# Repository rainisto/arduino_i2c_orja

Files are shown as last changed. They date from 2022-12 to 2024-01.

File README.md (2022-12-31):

# arduino_i2c_orja
Danfoss heat pump USB based control interface, which mimics ThermIQ-USB functionality.

# Background

In 2015 I did a blog post where I reverse engineered the i2c protocol which Dandfoss and Thermia pumps are using (sorry post is in Finnish):

https://omakotikotitalomme.blogspot.com/2015/03/danfoss-lampopumpun-salaisuudet.html    

And finally I decided that its time to open source the source code and release updated gerber files which makes it easier to use (with Arduino Nano or Arduino pro mini). Hopefully this will allow cheap alternatives for controlling Danfoss heap pumps. Use at your own risk, don't blame me if you break your device. Always turn off the devices before connecting the i2c cable.    

I know that the code is not very beatiful and optimized, but it works. If you find bugs feel free to make merge request with a fix. Unfortunately I'm currently not able to give much support for this project, as I'm focusing on coding ESP32 based version which will add wifi and ROOM thermometer emulation support (similar functionality as MQTT based ThermIQ-ROOM2LP).

# Software alternatives for usage

Implementation has been tested with taloLogger, ThermIQ and ThermIQ2-Web. Please don't ask support from thermiq.net as this is not their hardware (so there is no official support for it) this just happends to mimic the same AT-command functionality. I've been running it 5+ years without problems. And of course you can use for example minicom to run AT-commands manually.

TaloLogger instructions:    
- https://olammi.iki.fi/sw/taloLoggerPi/howto.php     
- https://olammi.iki.fi/sw/taloLogger/

V1 version install instructions:    
- https://www.thermiq.net/wp-conteny/uploads/ThermIQ-installation-for-Raspberry-PI.pdf  (does not require license)

V2 version install instructions:    
- https://www.thermiq.net/en/sw/raspberry-pi/ (requires license which can be purchased from https://www.thermiq.net/en/produkt/thermiq2-web/ )

In theory it should also work with home assistant integration (but I haven't had time to test it):    
- https://github.com/tomrosenback/thermiq-node-red-homeassistant-config    
- https://github.com/ThermIQ/thermiq_mqtt-ha

# Building arduino hex firmware on Linux with Docker

You need to have Docker installed on your Linux machine and then run:

- ./linux_build.sh    

Resulting .hex files will be found under hex-directory after the build. You can use for example avrdude to flash it:    
- avrdude -v -p atmega328p -c arduino -P /dev/ttyUSB0 -b 57600 -D -U flash:w:i2c_rtc_simplified_with_watchdog_nano.ino.hex:i

# Building with Arduino IDE (Linux and Windows):
Install package depencies (Wire, NeoSWSerial and AltSoftSerial) before the build.

# Hardware with gerber pcb

Arduino Nano is prefered over Arduino Pro mini and serial ttl adapter, as its cheaper just to use Arduino Nano to power the device as compared to Pro mini and serial ttl adapter. Serial2 and Serial3 are optional adapters which can be used for example if you want to simultaneously use several serial connections with TaloLogger and ThermIQ web interfaces at the same time. Nano variant use 220uF capacitor to prevent rebooting when connecting to 1st serial port (unplug the capacitor during firmware flashing).

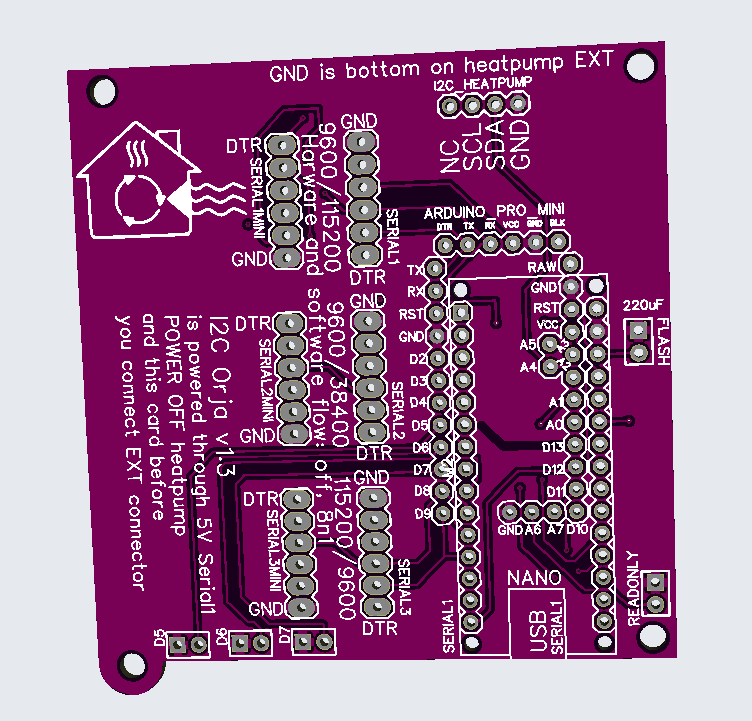
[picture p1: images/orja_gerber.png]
Orja Gerber


There is RO pins for ReadOnly mode (if you want to prevent write commands and are only gathering usage data).    
And there are serial speed controlling pins for switching between serial speeds (but most likely you want to stay at 9600 if you want to use the existing software backends).

There is a stl file for simple 3d printed screw-mount which will help protecting against short circuits against metal parts.

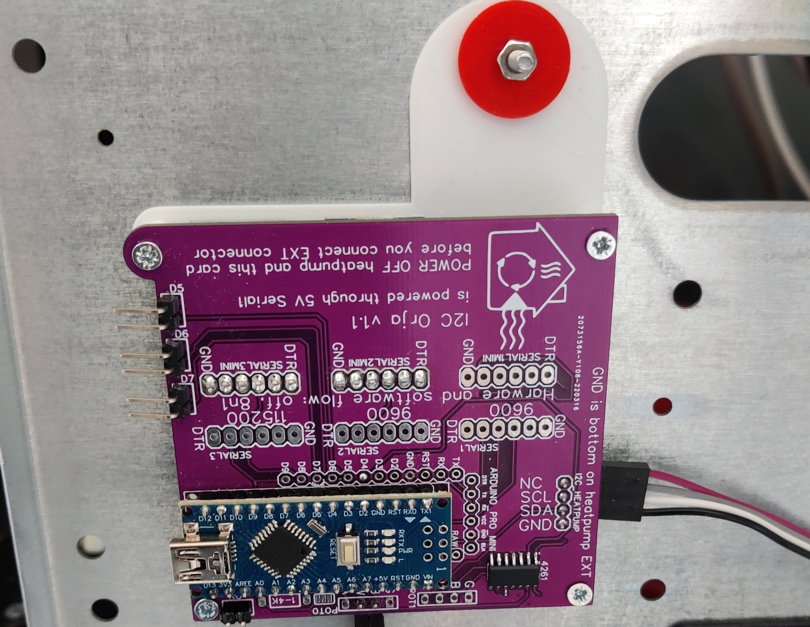
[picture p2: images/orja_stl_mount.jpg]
Orja Mount

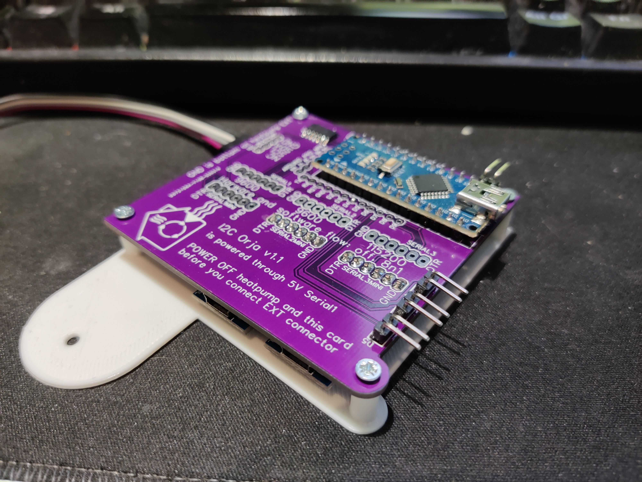
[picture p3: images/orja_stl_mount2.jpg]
Orja Mount2

Orja Mount3

# BOM

BOM is around 10-20euroes depending where you source the hardware.

- Arduino Nano (recommended) or Arduino Pro mini (5V 16Mhz)    
- Serial ttl usb adapter(s) 5V (optional)    
- 4p dupont cable (for i2c connection)    
- 2.54mm header angle pins   
- 220uF capacitor for preventing Nano reseting when starting serial connection.

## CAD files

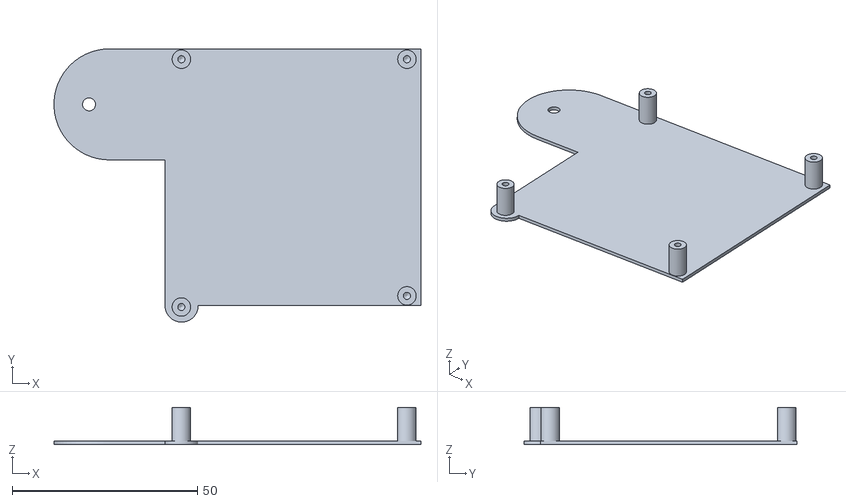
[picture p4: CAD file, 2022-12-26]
hardware/stl/I2C_orja.stl
99.2 x 73.8 x 10.0

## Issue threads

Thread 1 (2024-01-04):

Register 7F?

jukkapirinen, 2024-01-04:
I just started testing this, I can read the data but getting spammed with the data for register 7F all the time.

What is this register 7F (127) and value 0002?
And what are those empty requests?

```
$ cat /dev/serial/by-id/usb-1a86_USB_Serial-if00-port0 |ts  '%Y%m%d-%H:%M:%.S'
20240105-00:52:04.371242 7F=0002
20240105-00:52:04.371347 empty request
20240105-00:52:04.371390 7F=0002
20240105-00:52:04.371422 7F=0002
20240105-00:52:04.371451 7F=0002
20240105-00:52:04.371481 7F=0002
20240105-00:52:04.688652 7F=0002
20240105-00:52:04.688732 7F=0002
20240105-00:52:04.688756 empty request
20240105-00:52:04.688776 empty request
20240105-00:52:05.164298 7F=0002
20240105-00:52:05.164427 7F=0002
20240105-00:52:05.164474 7F=0002
20240105-00:52:05.164512 7F=0002
20240105-00:52:05.164577 7F=0002
20240105-00:52:05.164612 7F=0002
20240105-00:52:05.164646 7F=0002
20240105-00:52:05.243292 7F=0002
20240105-00:52:05.243397 7F=0002
20240105-00:52:05.243430 7F=0002
20240105-00:52:05.243456 7F=0002
20240105-00:52:05.243481 7F=0002
20240105-00:52:05.243509 7F=0002
20240105-00:52:05.243535 7F=0002
20240105-00:52:05.408361 7F=0002
20240105-00:52:05.408489 7F=0002
20240105-00:52:05.408548 7F=0002
20240105-00:52:05.408582 7F=0002
20240105-00:52:05.408612 7F=0002
20240105-00:52:05.408641 empty request
20240105-00:52:05.487329 7F=0002
20240105-00:52:05.487399 7F=0002
20240105-00:52:05.487414 7F=0002
20240105-00:52:05.487426 7F=0002
20240105-00:52:05.487438 7F=0002
20240105-00:52:05.487448 7F=0002
20240105-00:52:05.487459 7F=0002
```

rainisto, 2024-01-04:
7f is max register, maybe you have accidentally asked that value, and request is not cleared. Maybe off by one bug in code, as usually 74 is the last register that has usable data. What kind of query steps have you made to trigger that? empty request is just debug if wire library doesn't have data. So might also be arduino ide or library version issue.

jukkapirinen, 2024-01-05:
Yes that fixes the initialize, but the real issue was that the readQueue array was too small (0-127= 128) and created infinite loop.

int readQueue[MAX_REGISTER + 1];

https://github.com/jukkapirinen/arduino_i2c_orja/commit/e5ff0c0d8ccd08068f233ab1cf81ee704d306a35

jukkapirinen, 2024-01-05:
And I did not ask for that value or any value. Just connected to pump and then cat / screen to view the serial output. However now it works with the above changes and also got working with Home Assistant + NodeRED + ThermIQ MQTT Integration

rainisto, 2024-01-05:
Thanks for the info, I pushed fix to git.

Closed 2024-01-05.

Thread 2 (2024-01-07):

Room sensor emulation

andresmihkelson, 2024-01-07:
Thank You for all the good work on reverse engineering the I2C communication on the EXT port.

You have mentioned in couple of forums that You also got the indoor room sensor interface (pins 303/304) working. Can You share any details on how it is implemented?

rainisto, 2024-01-07:
It will be 2 part blog post, second part will still take some more time before its ready for publishing. But I guess the 1 / 2 part is ready (so I published it now) which will tell the logic analyzing and solving out that it was Manchester code variant and how the protocol works in paper. Its in Finnish so you'll need to use google translator. https://omakotikotitalomme.blogspot.com/2024/01/danfoss-sisalampotilasensorin.html

andresmihkelson, 2024-01-07:
Thanks!

Closed 2024-01-07.

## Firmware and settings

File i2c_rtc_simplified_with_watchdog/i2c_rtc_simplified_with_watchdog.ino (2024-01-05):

/* 
 * This file is part of the Arduino i2c orja distribution (https://github.com/rainisto/arduino_i2c_orja)
 * Copyright (c) 2015-2022 Jonni Rainisto (rainisto@iki.fi)
 * 
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
 * You should have received a copy of the GNU General Public License 
 * along with this program. If not, see <http://www.gnu.org/licenses/>.
 */

#include <Wire.h>
#include <AltSoftSerial.h>
#include <NeoSWSerial.h>
#include <avr/wdt.h>

NeoSWSerial serial2(3,4);    // RX, TX
AltSoftSerial serial3;       // 8, 9

enum { 
  I2C_CMD_PING_BOOT = 0xfd,
  I2C_CMD_PING_QUERY = 0xfe
};
extern const byte supportedI2Ccmd[] = { 
  I2C_CMD_PING_BOOT, I2C_CMD_PING_QUERY
};

enum { 
  I2C_MSG_ARGS_MAX = 3,
  I2C_RESP_LEN_MAX = 3
};
#define TWI_FREQ_SETTING         400000L       // 400KHz for I2C
#define CPU_FREQ                 16000000L     // 16MHz
#define SLAVE_ADDRESS            0x2e
byte zero = 0x00;                              //workaround for issue #527
#define MAX_REGISTER             0x7F
byte previousRequest=0x0;

byte writeMask=0x80;
byte writeAddress=0x0;
byte writeHigh=0x0;
byte writeLow=0x0;
int writeOrigin=0;
int roPinValue=0;

int okPending=0;

int readQueue[MAX_REGISTER+1];

int argsCnt = 0;                        // how many arguments were passed with given command
int requestedCmd = -1;                  // which command was requested (if any)

byte i2cArgs[I2C_MSG_ARGS_MAX];         // array to store args received from master
int i2cArgsLen = 0;                     // how many args passed by master to given command

uint8_t i2cResponse[I2C_RESP_LEN_MAX];  // array to store response
int i2cResponseLen = 0;                 // response length

void setup()
{
  delay(1000); 
  // TWBR = ((CPU_FREQ / TWI_FREQ_SETTING) - 16) / 2;
  Wire.begin(SLAVE_ADDRESS);
  int i;

  // Initialize readQueue
  for (i=0; i <= MAX_REGISTER; i++) {
    readQueue[i]=0;
  }
  // config pins
  pinMode(5, INPUT_PULLUP);
  pinMode(6, INPUT_PULLUP);
  pinMode(7, INPUT_PULLUP);

  // Initialize serial ports
  if (digitalRead(5)) {
    Serial.begin(9600);
  } else {
    Serial.begin(115200);
  }
  Serial.println(F("\nI2C Orja v1.0 (serial1)"));
  if (digitalRead(6)) {
    serial2.begin(9600);
  } else {
    serial2.begin(38400);
  }
  serial2.println(F("\nI2C Orja (serial2)"));
  if (digitalRead(7)) {
    serial3.begin(115200);
  } else {
    serial3.begin(9600);
  }
  serial3.println(F("\nI2C Orja (serial3)"));

  Wire.onRequest(requestEvent); // register event handlers
  Wire.onReceive(receiveEvent); // register event handlers
  wdt_enable(WDTO_8S);          // enable watchdog
}

byte getVal(char c)
{
   if(c >= '0' && c <= '9') return (byte)(c - '0');
   else return (byte)(c-'A'+10);
}

void requestEvent(){
  Wire.write(i2cResponse, i2cResponseLen);
}

void receiveEvent(int howMany)
{
  int cmdRcvd = -1;
  int argIndex = -1; 
  argsCnt = 0;

  if (Wire.available()) {
    cmdRcvd = Wire.read();                       // receive first byte - command assumed
    while (Wire.available()) {                   // receive rest of tramsmission from master assuming arguments to the command
      if (argIndex < I2C_MSG_ARGS_MAX){
        argIndex++;
        i2cArgs[argIndex] = Wire.read();
      } else {
        Serial.println(F("Too many arguments")); // only printing errors to main serial
        return;
      }
      argsCnt = argIndex+1;  
    }
  } else {
    Serial.println(F("empty request"));
    return;
  }
  // validating command is supported by slave
  int fcnt = -1;
  //for (int i = 0; i < sizeof(supportedI2Ccmd); i++) { // cast to avoid compiler warning
  for (int i = 0; i < (int)sizeof(supportedI2Ccmd); i++) {
    if (supportedI2Ccmd[i] == cmdRcvd) {
      fcnt = i;
    }
  }
  if (cmdRcvd >= 0 && cmdRcvd <= MAX_REGISTER) fcnt = cmdRcvd;

  if (fcnt<0){
    Serial.print(F("command not supported:"));
    Serial.println(cmdRcvd);
    return;
  }
  requestedCmd = cmdRcvd;
  // now main loop code should pick up a command to execute and prepare required response when master waits before requesting response
}

// buffer to each serial port
String inData;
String inData2;
String inData3;

void loop()
{
  wdt_reset(); // prevent watchdog from rebooting
  int hits=0;

  // if heatpump asks that do I need to query anything
  if (requestedCmd == I2C_CMD_PING_BOOT || requestedCmd == I2C_CMD_PING_QUERY) {
    int i;
    // Iterate over all registers and any of the serials have raised interest to specific register value, then
    // append it to i2cResponse (so we ask pump to return those values).
    for (i=0; i <= MAX_REGISTER; i++) {
      if (readQueue[i]>0) {
        i2cResponseLen = 0;
        i2cResponseLen++;
        i2cResponse[i2cResponseLen -1] = i;
        hits=1;
        okPending=readQueue[i]; // mark okPending to indicate that we are waiting for response for found register number
        break;
      }  
    }
    // if ATW has triggered writeAdress and there is no read requests on the queue, then we can ask for write
    // a value to specific register address
    if (writeAddress && hits==0) {
      okPending=writeOrigin; // informs which serial interface is waiting OK message for the write command
      hits=1;
      i2cResponseLen = 0;
      i2cResponseLen++;
      i2cResponse[i2cResponseLen -1] = writeAddress;
      i2cResponseLen++;
      i2cResponse[i2cResponseLen -1] = writeLow;
      i2cResponseLen++;
      i2cResponse[i2cResponseLen -1] = writeHigh;
      // clear write request afterwards
      writeAddress=0x0;
      writeLow=0x0;
      writeHigh=0x0;
      writeOrigin=0;
    }
    if (hits==0) {
      // when there is no more read or write commands pending then print OK to serial consoles that
      // were issuing commnds (resolved by bitfield in okPenging so &1, &2 and &4)
      i2cResponseLen = 0;
      i2cResponseLen++;
      i2cResponse[i2cResponseLen -1] = 0xFF; // 0xFF == I don't need any more data currently
      if (okPending) {
        if (okPending&1) Serial.println(F("OK\n"));
        if (okPending&2) serial2.println(F("OK\n"));
        if (okPending&4) serial3.println(F("OK\n"));
        okPending=0;
      }
    }
    requestedCmd = -1;   // set requestd cmd to -1 disabling processing in next loop
  } else if (requestedCmd >= 0 && requestedCmd <= MAX_REGISTER){
    // log the requested function is unsupported (e.g. by writing to serial port or soft serial)
    // requestedCmd is registerNumber+"="+value(high+low) bytes
    // If will check which serial terminal was interested about the received register value
    // and then prints it if there is a match
    if (readQueue[requestedCmd]&1) {
      if (requestedCmd<16) Serial.print(F("0"));
      Serial.print(requestedCmd, HEX); 
      Serial.print(F("="));
      if (i2cArgs[1]<16) Serial.print(F("0"));
      Serial.print(i2cArgs[1], HEX);
      if (i2cArgs[0]<16) Serial.print(F("0"));
      Serial.println(i2cArgs[0], HEX);
    }
    if (readQueue[requestedCmd]&2) {
      if (requestedCmd<16) serial2.print(F("0"));
      serial2.print(requestedCmd, HEX); 
      serial2.print(F("="));
      if (i2cArgs[1]<16) serial2.print(F("0"));
      serial2.print(i2cArgs[1], HEX);
      if (i2cArgs[0]<16) serial2.print(F("0"));
      serial2.println(i2cArgs[0], HEX);
    }
    if (readQueue[requestedCmd]&4) {
      if (requestedCmd<16) serial3.print(F("0"));
      serial3.print(requestedCmd, HEX); 
      serial3.print(F("="));
      if (i2cArgs[1]<16) serial3.print(F("0"));
      serial3.print(i2cArgs[1], HEX);
      if (i2cArgs[0]<16) serial3.print(F("0"));
      serial3.println(i2cArgs[0], HEX);
    }
    readQueue[requestedCmd]=0;
    requestedCmd = -1;   // set requestd cmd to -1 disabling processing in next loop
  }

  // iterative code for each serial interface
  handle_serial(Serial , inData , 1);
  handle_serial(serial2, inData2, 2);
  handle_serial(serial3, inData3, 4);

}

void handle_serial(Stream &serialport, String &input_data, int bit_id ) {
  while (serialport.available() > 0)
  {
    char recieved = serialport.read();
    if (input_data.length() > 0 && (recieved == 8 || recieved == 127)) {
      input_data[input_data.length()]=0;
    } else {
      input_data += recieved;
    }
    serialport.print(recieved); // local echo
    // Process message when new line character is recieved
    if (recieved == '\n' && input_data.length()<2) {
      input_data="";
      recieved=0;
    }
    if (recieved == '\r' || recieved == '\n' || input_data.length() > 25)
    {
      if (recieved == '\r') serialport.println(); // remove if it bothers
      input_data.toUpperCase();
      if (input_data.substring(0,3).equalsIgnoreCase("ATI")) {
        // Fake that we are ThermIQ device
        serialport.println(F("ThermIQ2 v.4.30 0011"));
        serialport.println(F("OK\n"));
      } else if (input_data.substring(0,3).equalsIgnoreCase("ATR")) {
        int pituus = input_data.substring(3).length();
        byte start = getVal(input_data[4]) + (getVal(input_data[3]) << 4);
        if (start > MAX_REGISTER) { serialport.println(F("NO\n")); input_data = ""; return; }   // error handling
        readQueue[start]=readQueue[start]|bit_id;
        if (pituus > 4) {
          byte untill = getVal(input_data[6]) + (getVal(input_data[5]) << 4);
          if (untill > MAX_REGISTER) { serialport.println(F("NO\n")); input_data = ""; return; } // error handling
          int i;
          for (i=start+1; i <= untill; i++) {
            readQueue[i]=readQueue[i]|bit_id;
          }
          if (pituus > 8) {
            start = getVal(input_data[8]) + (getVal(input_data[7]) << 4);
            if (start > MAX_REGISTER) { serialport.println(F("NO\n")); input_data = ""; return; } // error handling
            untill = getVal(input_data[10]) + (getVal(input_data[9]) << 4);
            if (untill > MAX_REGISTER) { serialport.println(F("NO\n")); input_data = ""; return; } // error handling
            int i;
            for (i=start; i <= untill; i++) {
              readQueue[i]=readQueue[i]|bit_id;
            }
          }
        }
      } else if (input_data.substring(0,3).equalsIgnoreCase("ATW")&&(analogRead(A6) > 100)) {
        // atwxxhhll               Write hhll to register xx
        int pituus = input_data.substring(3).length();
        if (pituus > 6) {
          writeAddress = getVal(input_data[4]) + (getVal(input_data[3]) << 4);
          if (writeAddress < writeMask) writeAddress = writeAddress + writeMask;
          writeHigh = getVal(input_data[6]) + (getVal(input_data[5]) << 4);
          writeLow = getVal(input_data[8]) + (getVal(input_data[7]) << 4);
          writeOrigin = bit_id;
        }
      } else if (input_data.substring(0,3).equalsIgnoreCase("ATB")) {
        serialport.println(F("Not supported in this emulation"));
        serialport.println(F("NO\n"));
      } else if (input_data.substring(0,3).equalsIgnoreCase("ATP")) {
        serialport.println(F("Protect pin state"));
        roPinValue=analogRead(A6);
        serialport.println(roPinValue);
        serialport.println(F("OK\n"));
      } else if (input_data.substring(0,4).equalsIgnoreCase("ATL?")) {
        serialport.println(F("1"));
        serialport.println(F("OK"));
      } else if (input_data.substring(0,4).equalsIgnoreCase("ATTG")) {
        serialport.println(F("NO\n"));
      } else if (input_data.substring(0,4).equalsIgnoreCase("ATTS")) {
        serialport.println(F("NO\n"));
      } else {
        serialport.print(F("Received unknown command: "));
        serialport.println(input_data);
        serialport.println(F("NO\n"));
      }
      input_data = ""; // Clear recieved buffer
    }
  }
}

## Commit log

2022-12-26 Added gerbers and stl
    [I2C_orja.stl]
2024-01-04 Bugfix: initialize readQueue up to MAX_REGISTER
    [i2c_rtc_simplified_with_watchdog.ino]
2024-01-05 Bugfix: readQueue[MAX_REGISTER + 1]
    [i2c_rtc_simplified_with_watchdog.ino]
2026-11-09 Add CLAUDE.md
    Code overview for AI assistants: protocol flow, pins, build and gotchas.
2026-11-09 Bugfixes: i2cArgs bounds, okPending, backspace
    - i2cArgs bounds check off-by-one (4th arg was written past the array)
    - Accumulate okPending bits so concurrent serial ports get their OK
    - Backspace removes the last character

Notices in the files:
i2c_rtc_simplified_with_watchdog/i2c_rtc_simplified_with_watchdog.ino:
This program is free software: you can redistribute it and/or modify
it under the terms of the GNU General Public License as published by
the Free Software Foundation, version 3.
